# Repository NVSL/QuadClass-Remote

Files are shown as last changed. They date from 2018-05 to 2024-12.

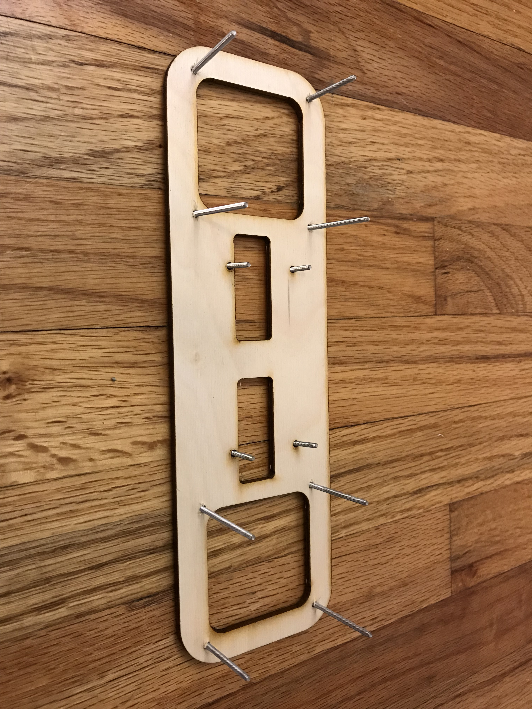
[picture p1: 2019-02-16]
images/IMG_7026.jpg

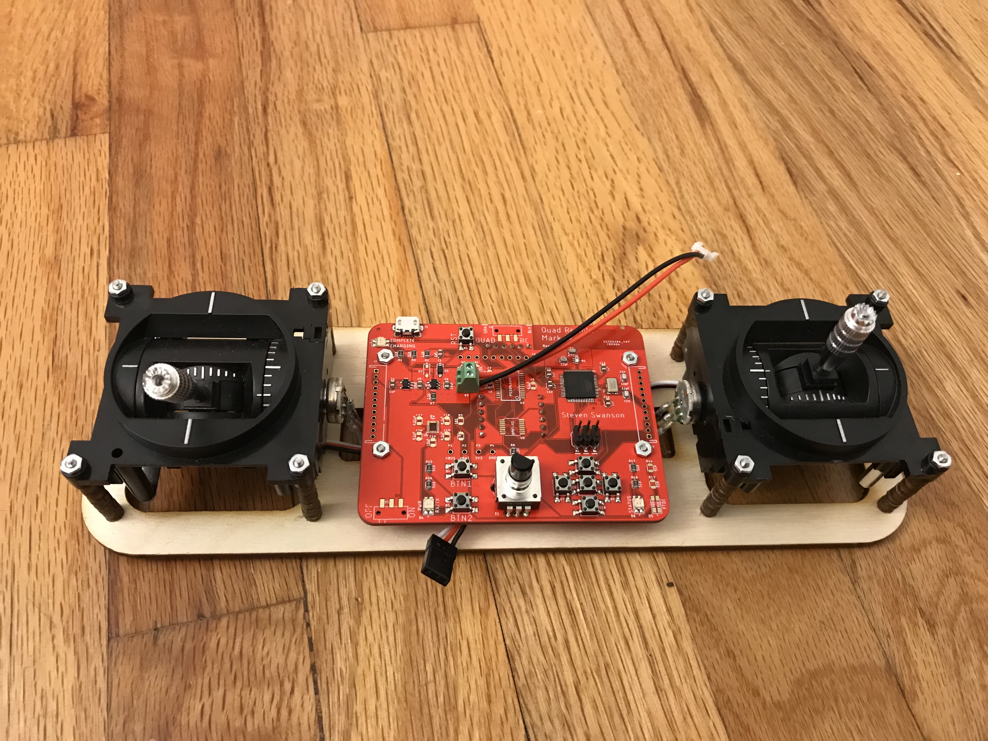
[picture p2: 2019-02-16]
images/IMG_7029.jpg

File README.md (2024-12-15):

# CSE176e Quad Remote

## Assembly

## Parts

All the parts are on the course unified BOM: https://docs.google.com/spreadsheets/d/1jt7lCU-Biuc4YyG8EaISPEg1VLbqKCh2ZZRz8jerXEI/edit?gid=0#gid=0

## Laser Cutting

The plywood base and the "donuts" used for standoffs are all in the
`.brd` file.  Open it, hide everything but the `baseplate` layer.
Print it to a PDF and feed it to your laser cutter.

The wooden parts are cut from 3mm plywood (see parts list).

## The Gimbals

The gimbals attach to the baseplate with the 8 long machine screws and 8 nuts.  

## Board

The control board mounts to the baseplate using the shorter screws and nuts.  Use 3 donuts to put space between the board and the baseplate.

## Battery Cable

Red is positive.

Attach the battery and tuck it under the board.  You can trim the battery cable, if you want.  Experiment with different lengths.

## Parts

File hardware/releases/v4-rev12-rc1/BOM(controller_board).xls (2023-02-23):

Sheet: bom-sample
Controller Board BOM Rev.11
Manufacturer | Manufacturer Part Number (required) | Designator (required) | Qty (required) | Description (required) | Case | SMD ,BGA,LCC,OR TH | Top/Bottom | points (number of contacts the IC has in each board) | Total points (number of contacts per BOM line has) | Comment | DIST | DISTPN
Yageo | RC0603JR-070RL | R7 | 1 | RES 0 OHM JUMPER 1/10W 0603 | 603 | SMD | Top | 2 | 2 |  | Digikey | 311-0.0GRCT-ND
Samsung Electro-Mechanics | DNP | C10, C17 | 2 | CAP CER 1UF 10V X5R 0603 | 603 | SMD | Top | 2 | 4 |  | Digikey | DNP
Texas Instruments | DNP | U1 | 1 | IC REG LINEAR 3.3V 150MA SC70-5 | SOT23-5 | SMD | Top | 5 | 5 |  | DIGIKEY | DNP
Yageo | CC0603BRNPO9BNR75 | C2 | 1 | CAP CER 0.75PF 50V NPO 0603 | 603 | SMD | Top | 2 | 2 |  | Digikey | 311-3843-1-ND
Panasonic Electronic Components | EXB-N8V221JX | R1 | 1 | RES ARRAY 4 RES 220 OHM 0804 | 804 | SMD | Top | 8 | 8 |  | DIGIKEY | Y10222CT-ND
TE Connectivity AMP Connectors | 1-1735446-2 | J2 | 1 | CONN HEADER VERT 12POS 2MM | N/A | TH | Top | 12 | 12 |  | Digikey | A100106-ND
TE Connectivity AMP Connectors | 1-1735446-2 | J3 | 1 | CONN HEADER VERT 12POS 2MM | N/A | TH | Top | 12 | 12 |  | Digikey | A100106-ND
AVX Corporation | 06036A220KAT2A | C3 | 1 | CAP CER 22PF 6.3V NP0 0603 | 603 | SMD | Top | 2 | 2 |  | Digikey | 478-11384-1-ND
NA | DNP | A1 | 1 | trace antenna | N/A | NONE | Top | 0 | 0 |  | N/A | DNP
Microchip Technology | ATMEGA128RFA1-ZU | U4 | 1 | IC RF TXRX+MCU 802.15.4 64VFQFN | 64-QFN | SMD | Top | 64 | 64 |  | Digikey | ATMEGA128RFA1-ZU-ND
Amphenol ICC (FCI) | 95278-101A06LF | J4 | 1 | CONN HEADER SMD 6POS 2.54MM | N/A | SMD | Top | 6 | 6 |  | Digikey | 609-3487-1-ND
Wurth Electronics Inc. | 748421245 | B2 | 1 | BALUN 2.4GHZ-2.5GHZ 50/100 0805 | 805 | SMD | Top | 6 | 6 |  | Digikey | 732-2230-1-ND
Wurth Electronics Inc. | 691210910002 | B3 | 1 | TERM BLOCK 2P HORIZON 2.54MM PCB | N/A | TH | Top | 2 | 2 |  | Digikey | 732-691210910002-ND
Abracon LLC | ABM8-16.000MHZ-B2-T | Y1 | 1 | CRYSTAL 16.0000MHZ 18PF SMD | 4-SMD | SMD | Top | 4 | 4 |  | DIGIKEY | 535-9134-1-ND
NXP USA Inc. | NX3L2467PW,118 | U5 | 1 | IC ANALOG SWITCH DPDT 16TSSOP | 16-TSSOP | SMD | Top | 16 | 16 |  | DIGIKEY | 568-5300-1-ND
FTDI | FT232RL-REEL | U3 | 1 | USB FULL SPEED TO SERIAL UART IC | 28-SSOP | SMD | Top | 28 | 28 |  | DIGIKEY | 768-1007-1-ND
Samtec Inc. | TSM-102-01-L-DH | J6 | 1 | CONN HEADER SMD R/A 4POS 2.54MM | N/A | SMD | Top | 4 | 4 |  | DIGIKEY | SAM15344-ND
Harwin Inc. | DNP | JP1 | 1 | CONN HEADER SMD R/A 6POS 2.54MM | N/A | SMD | Bottom | 6 | 6 |  | DIGIKEY | DNP
On Shore Technology Inc. | DNP | J8 | 1 | TERM BLK 2P SIDE ENT 2.54MM PCB | N/A | TH | Top | 2 | 2 |  | Digikey | DNP
Sullins Connector Solutions | DNP | J9 | 1 | CONN HDR 12POS 0.1 TIN PCB | N/A | TH | Top | 12 | 12 |  | DIGIKEY | DNP
Microchip Technology | MCP73831T-2ACI/OT | U2 | 1 | IC CONTROLLR LI-ION 4.2V SOT23-5 | SOT23-5 | SMD | Top | 5 | 5 |  | DIGIKEY | MCP73831T-2ACI/OTCT-ND
Bourns Inc. | PEC12R-4220F-S0024 | E1 | 1 | ROTARY ENCODER MECHANICAL 24PPR | N/A | TH | Top | 7 | 7 |  | DIGIKEY | PEC12R-4220F-S0024
None | DNP | F1 | 1 | SHORT | N/A | NONE | Top | 0 | 0 |  | N/A | DNP
Sullins Connector Solutions | NPPC101KFXC-RC | L1 | 1 | 10 Position Header, Top or Bottom Entry Connector Surface Mount | N/A | SMD | Top | 10 | 10 |  | Digikey | S5641-ND
Amphenol ICC (FCI) | 10118192-0001LF | J1 | 1 | CONN RCPT USB2.0 MICRO B SMD R/A | USB-microB | SMD | Top | 7 | 7 |  | DIGIKEY | 609-4613-1-ND
Panasonic Electronic Components | EXB-N8V152JX | R4, R5 | 2 | RES ARRAY 4 RES 1.5K OHM 0804 | 804 | SMD | Top | 8 | 16 |  | DIGIKEY | Y10152CT-ND
Vishay Vitramon | VJ0603A120FXQCW1BC | C14, C15 | 2 | CAP CER 12PF 10V C0G/NP0 0603 | 603 | SMD | Top | 2 | 4 |  | Digikey | 720-1655-1-ND
Toshiba Semiconductor and Storage | CRS08(TE85L,Q,M) | D2, D3 | 2 | DIODE SCHOTTKY 30V 1.5A SFLAT | SOD-123F | SMD | Top | 2 | 4 |  | Digikey | CRS08QMCT-ND
Molex | 532610671 | J5, J7 | 2 | CONN HEADER SMD R/A 6POS 1.25MM | N/A | SMD | Top | 6 | 12 |  | DIGIKEY | WM7624CT-ND
C&K | JS202011JCQN | S1, S2 | 2 | SWITCH SLIDE DPDT 300MA 6V | N/A | SMD | Top | 6 | 12 |  | DIGIKEY | CKN10723CT-ND
Panasonic Electronic Components | EXB-N8V103JX | R2, R3, R6 | 3 | RES ARRAY 4 RES 10K OHM 0804 | 804 | SMD | Top | 8 | 24 |  | DIGIKEY | Y10103CT-ND
KEMET | C0603C104K8RACTU | C1, C8, C9 | 3 | CAP CER 0.1UF 10V X7R 0603 | 603 | SMD | Top | 2 | 6 |  | Digikey | 399-1095-1-ND
Samsung Electro-Mechanics | CL10A106MQ8NNNC | C5, C6, C7 | 3 | CAP CER 10UF 6.3V X5R 0603 | 603 | SMD | Top | 2 | 6 |  | Digikey | 1276-1119-1-ND
Lite-On Inc. | LTST-C195TGKRKT | D1, D4, D5, D6 | 4 | LED GREEN/RED CLEAR CHIP SMD | 4-SMD | SMD | Top | 4 | 16 |  | DIGIKEY | 160-2252-1-ND
Samsung Electro-Mechanics | CL10A105KP8NNNC | C4, C11, C12, C13, C16 | 5 | CAP CER 1UF 10V X5R 0603 | 603 | SMD | Top | 2 | 10 |  | Digikey | 1276-1182-1-ND
E-Switch | TL3305AF160QG | B1, B4, B5, B6, B7, B8, B9, B10 | 8 | SWITCH TACTILE SPST-NO 50MA 12V | N/A | SMD | Top | 4 | 32 |  | DIGIKEY | EG5350CT-ND
NA | DNP | V1, V2, V3, V4, V5, V6, V7, V8, V23, V24, V26, V27, V28, V30, V31, V32, V33, V34, V35, V36, V37, V38 | 22 | N/A | N/A | NONE | Top | 0 | 0 |  | N/A | DNP

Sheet: (ignore)4_Digikey-BOM
4 | 311-3843-1-ND | (controller_board) Yageo
4 | Y10222CT-ND | (controller_board) Panasonic Electronic Components
4 | A100106-ND | (controller_board) TE Connectivity AMP Connectors
4 | A100106-ND | (controller_board) TE Connectivity AMP Connectors
4 | 478-11384-1-ND | (controller_board) AVX Corporation
4 | DNP | (controller_board) NA
4 | ATMEGA128RFA1-ZU-ND | (controller_board) Microchip Technology
4 | 609-3487-1-ND | (controller_board) Amphenol ICC (FCI)
4 | 732-2230-1-ND | (controller_board) Wurth Electronics Inc.
4 | 732-691210910002-ND | (controller_board) Wurth Electronics Inc.
4 | 535-9134-1-ND | (controller_board) Abracon LLC
4 | 568-5300-1-ND | (controller_board) NXP USA Inc.
4 | 768-1007-1-ND | (controller_board) FTDI
4 | SAM15344-ND | (controller_board) Samtec Inc.
4 | DNP | (controller_board) Harwin Inc.
4 | DNP | (controller_board) On Shore Technology Inc.
4 | DNP | (controller_board) Sullins Connector Solutions
4 | MCP73831T-2ACI/OTCT-ND | (controller_board) Microchip Technology
4 | PEC12R-4220F-S0024 | (controller_board) Bourns Inc.
4 | DNP | (controller_board) None
4 | S5641-ND | (controller_board) Sullins Connector Solutions
4 | 609-4613-1-ND | (controller_board) Amphenol ICC (FCI)
8 | Y10152CT-ND | (controller_board) Panasonic Electronic Components
8 | 720-1655-1-ND | (controller_board) Vishay Vitramon
8 | CRS08QMCT-ND | (controller_board) Toshiba Semiconductor and Storage
8 | WM7624CT-ND | (controller_board) Molex
8 | CKN10723CT-ND | (controller_board) C&K
12 | Y10103CT-ND | (controller_board) Panasonic Electronic Components
12 | 399-1095-1-ND | (controller_board) KEMET
12 | 1276-1119-1-ND | (controller_board) Samsung Electro-Mechanics
16 | 160-2252-1-ND | (controller_board) Lite-On Inc.
20 | 1276-1182-1-ND | (controller_board) Samsung Electro-Mechanics
32 | EG5350CT-ND | (controller_board) E-Switch
88 | DNP | (controller_board) NA

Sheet: (ignore)50_Digikey-BOM
50 | 311-3843-1-ND | (controller_board) Yageo
50 | Y10222CT-ND | (controller_board) Panasonic Electronic Components
50 | A100106-ND | (controller_board) TE Connectivity AMP Connectors
50 | A100106-ND | (controller_board) TE Connectivity AMP Connectors
50 | 478-11384-1-ND | (controller_board) AVX Corporation
50 | DNP | (controller_board) NA
50 | ATMEGA128RFA1-ZU-ND | (controller_board) Microchip Technology
50 | 609-3487-1-ND | (controller_board) Amphenol ICC (FCI)
50 | 732-2230-1-ND | (controller_board) Wurth Electronics Inc.
50 | 732-691210910002-ND | (controller_board) Wurth Electronics Inc.
50 | 535-9134-1-ND | (controller_board) Abracon LLC
50 | 568-5300-1-ND | (controller_board) NXP USA Inc.
50 | 768-1007-1-ND | (controller_board) FTDI
50 | SAM15344-ND | (controller_board) Samtec Inc.
50 | DNP | (controller_board) Harwin Inc.
50 | DNP | (controller_board) On Shore Technology Inc.
50 | DNP | (controller_board) Sullins Connector Solutions
50 | MCP73831T-2ACI/OTCT-ND | (controller_board) Microchip Technology
50 | PEC12R-4220F-S0024 | (controller_board) Bourns Inc.
50 | DNP | (controller_board) None
50 | S5641-ND | (controller_board) Sullins Connector Solutions
50 | 609-4613-1-ND | (controller_board) Amphenol ICC (FCI)
100 | Y10152CT-ND | (controller_board) Panasonic Electronic Components
100 | 720-1655-1-ND | (controller_board) Vishay Vitramon
100 | CRS08QMCT-ND | (controller_board) Toshiba Semiconductor and Storage
100 | WM7624CT-ND | (controller_board) Molex
100 | CKN10723CT-ND | (controller_board) C&K
150 | Y10103CT-ND | (controller_board) Panasonic Electronic Components
150 | 399-1095-1-ND | (controller_board) KEMET
150 | 1276-1119-1-ND | (controller_board) Samsung Electro-Mechanics
200 | 160-2252-1-ND | (controller_board) Lite-On Inc.
250 | 1276-1182-1-ND | (controller_board) Samsung Electro-Mechanics
400 | EG5350CT-ND | (controller_board) E-Switch
1100 | DNP | (controller_board) NA

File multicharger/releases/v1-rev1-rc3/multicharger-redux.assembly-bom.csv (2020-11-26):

mfr | mfrpn | dist | distpn | part_list | qty | desc | substitute_ok | case | mounting | layer | pins | extended_pins | comments
Keystone Electronics | 931 | DIGIKEY | 36-931-ND | J2 | 1 | CONN PLUG USB2.0 TYPEA 4P SMD RA | no |  | SMD | top | 6 | 6
Microchip Technology | MCP73831T-2ACI/OT | DIGIKEY | MCP73831T-2ACI/OTCT-ND | U4 U1 | 2 | IC CONTROLLR LI-ION 4.2V SOT23-5 | no | SOT23-5 | SMD | top | 5 | 10
TDK | C2012X5R1E106K125AB | DIGIKEY | 490-5523-1-ND | C8 C3 C1 C6 | 4 | CAP CER 10UF 25V X5R 0805 | yes |  | SMD | top | 2 | 8
UNKNOWN | UNKNOWN | ALIBABA | https://www.alibaba.com/product-detail/Molex-51005-51006-2-pin-female_60863668004.html | B4 B1 | 2 | Surface mount battery connector | no |  | SMD | top | 4 | 8
Yageo | RC0805FR-071K2L | DIGIKEY | 311-1.20KCRCT-ND | R2 R3 R4 R1 | 4 | RES SMD 1.2K OHM 1% 1/8W 0805 | yes | 0805 | SMD | top | 2 | 8
YAGEO | AC0805FR-071K2L | DIGIKEY | YAG3700CT-ND | R7 R5 | 2 | RES SMD 1.2K OHM 1% 1/8W 0805 | yes | 0805 | SMD | top | 2 | 4
Lite-On Inc. | LTST-C195TGKRKT | DIGIKEY | 160-2252-1-ND | D4 D1 | 2 | LED GREEN/RED CLEAR CHIP SMD | no | 4SMD | SMD | top | 4 | 8

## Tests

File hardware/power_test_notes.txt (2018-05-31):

Design notes for RC1

1.  FTDI works ok, but only the green LED lights up.  Not sure why. -- Fixed
2.  The mux and switches work fine. 
3.  Battery charger seems to charge batteries, but LEDs don't light up.  I can light up green manually.  Red is a no go. -- fixed
4.  Some how blew C8. -- na
5.  Using PWREN to enable the battery charger may not be a good idea.  Will it work with a "wall wart" ***

6.  The solder stencil applied a little too much paste.  I had some bridges on ftdi and mux. -- make sure it's very flat to the board.  Works fine.
7.  When disconnected from USB and connected to power, VBAT sits at 2.7V.  -- powered via switch.
8.  When J5 is not connected to anything, D5 flashes for ever, which suggests that FTDI is resetting. -- unclear.
9.  Connecting VBAT ot FTDI via J5, causes slower flashing.  Maybe something capacitors and the mosfet?  -- unclear
10.  connecting VBUS to FTDI powers it correctly.

11.  The switch chip will drive it's vdd high if you connect power to pins, but leave VDD in floating.
12.  The polarity of my red leds is backwards. WTF???? *******

In order to use them FTDI voltage regulator, we have to have mosfet:  We are driving the FTDI with two different voltage sources: VBUS and VBAT (driven by charger), they are different, so one must be disconnected.  A diode by itself might do...  We can replace the pfet with a diode to prevent current from flowing back onto the battery from vbus.  This seems to work.

13.  The power switch needs to be in a different spot.  Turning it off disables ftdi when connected to VBUS.  Without vbus, FTDI red led is on a bit when switch is off.  Battery charge lites are both on a little --fixed

Current plan:

Assemble second board:

1.  DNP Diode, mosfet, and separate vreg.  mux, too.
2.  Test battery status voltage before assembly.
3.  Test red LEDs.  None of them work.  Did I overdrive them?  100Ohms at 5V > 32mA, which is 2mA over absolute max.  Try 200Ohms.  Shouldn't been a problem for batt charger because outut should be 5V-0.4 => 28mA
4.  Check whether wall wart charging works.

Red leds turn on nicely at 1.6V @ 6mA

V = IR
V = 5-1.6 = 3.4
I = 6mA 
R = V/I = 3.4/6e-3 = 566Ohms.  Using 510 for R6

For Battery charger:

4.6-1.6 = 3
I = 6mA
R = 500 Ohms.  Using 510 for R8

green leds light up nicely at 1.9V 5mA

V = 5-1.9 = 3.1
R = 3.1/5e-3 =620 Ohms

4.6 - 1.9 = 2.7
R = 2.7/5e-3 = 540Ohms

Using 510 for R9 R7

V = 3.3-1.9 = 1.4
R = 1.4=5e-3 = 280Ohms for power LED

Using 270 on R11

V=IR 
V=0.81
r = 510

I = V/R

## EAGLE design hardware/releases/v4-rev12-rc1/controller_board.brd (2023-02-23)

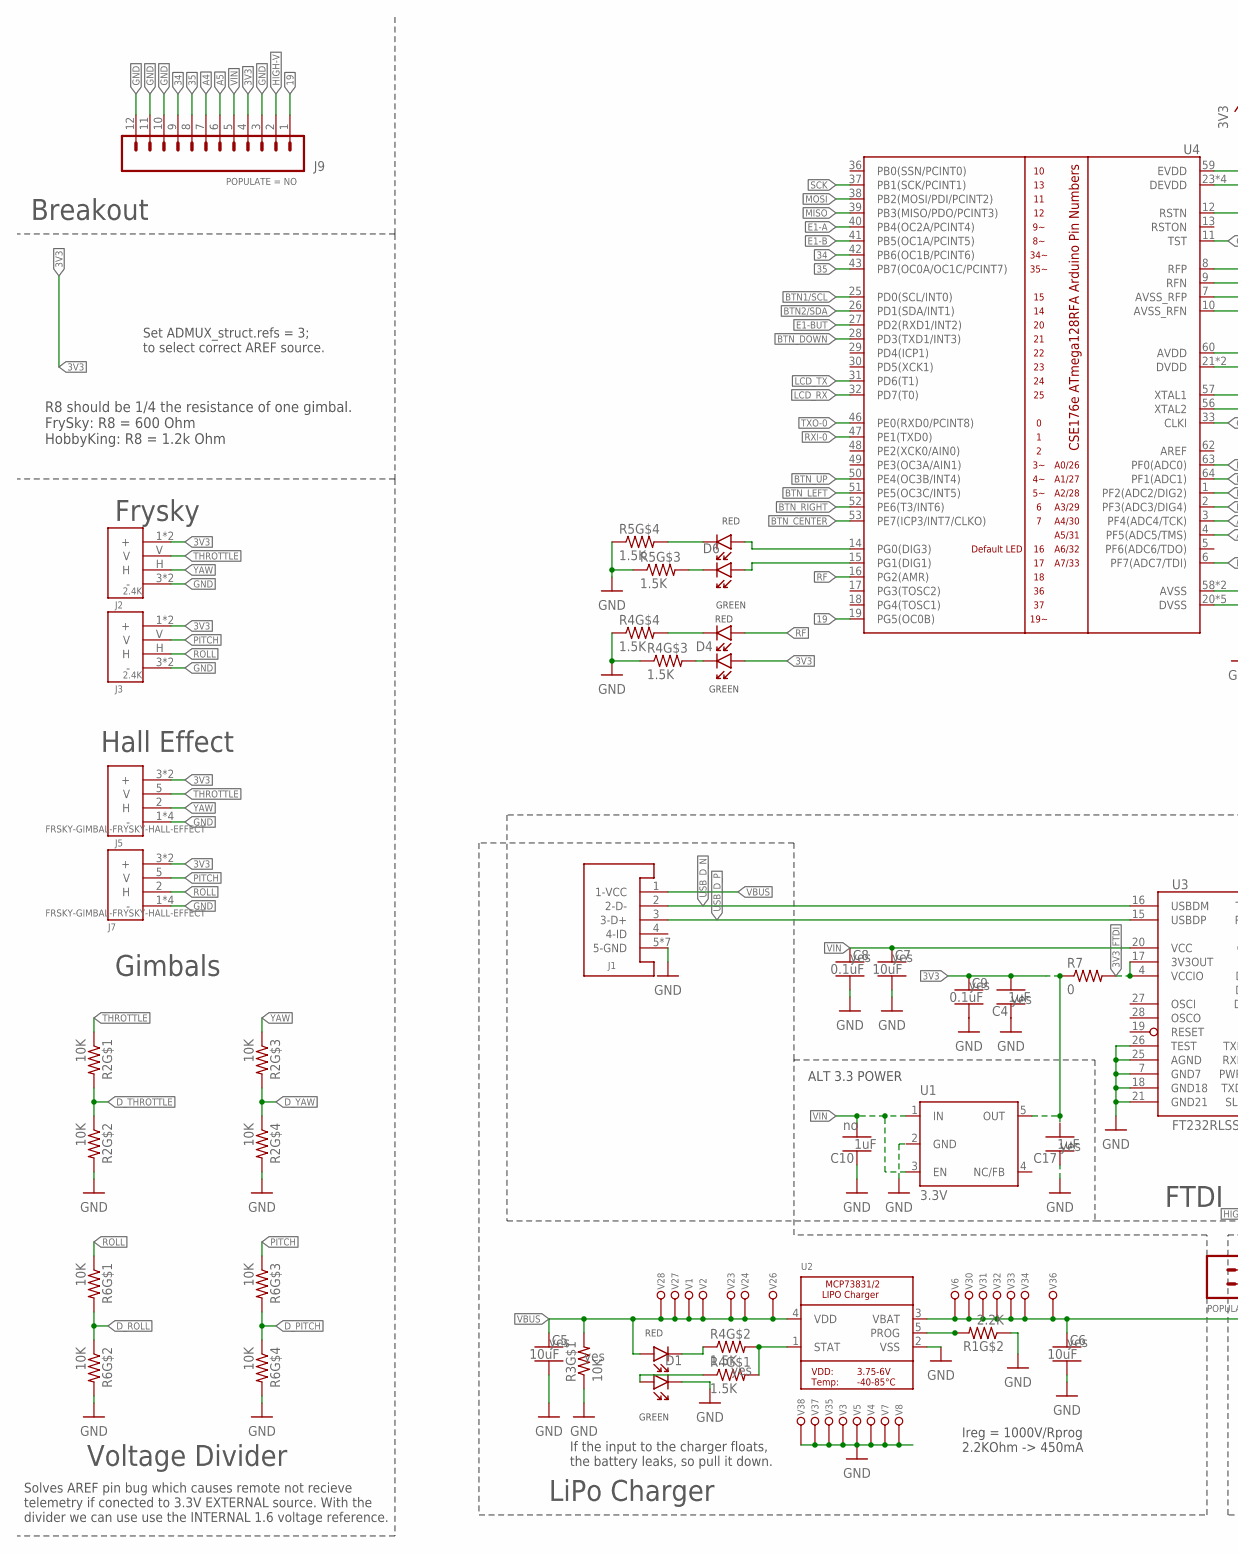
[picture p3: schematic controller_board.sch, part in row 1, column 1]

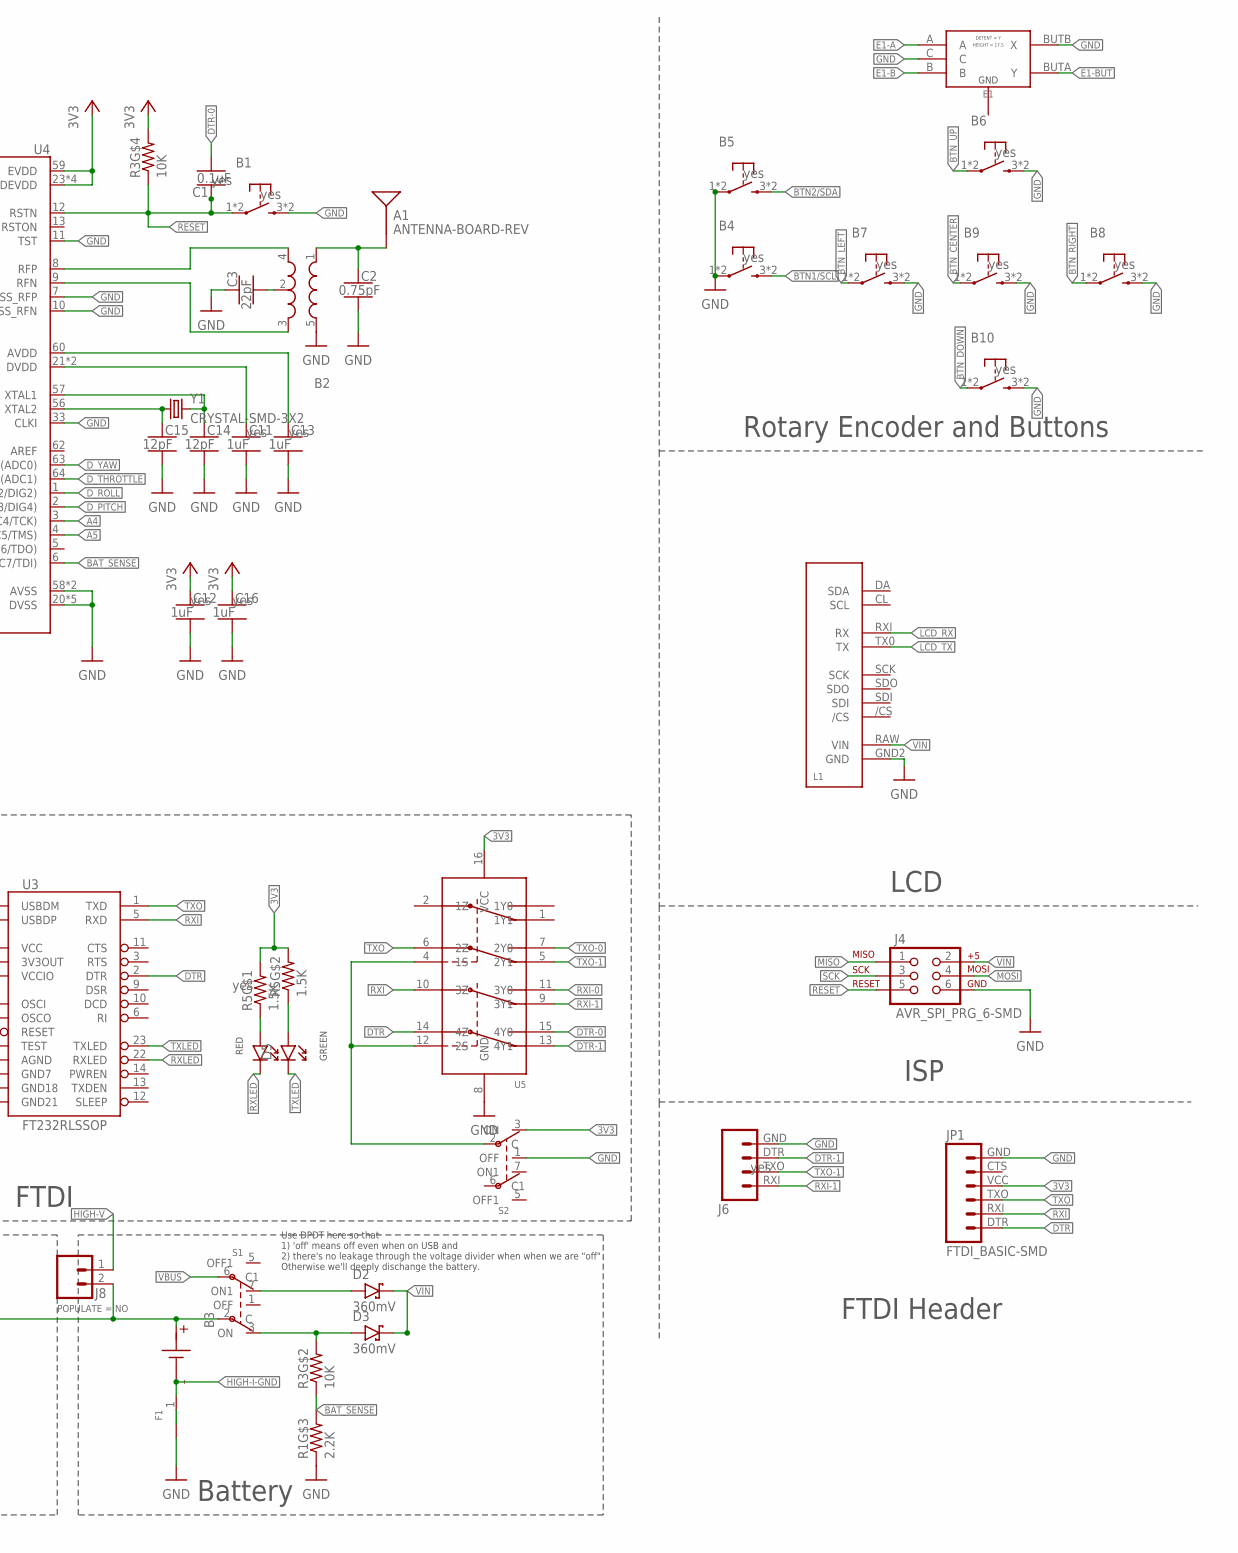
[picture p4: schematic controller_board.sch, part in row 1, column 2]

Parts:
A1: ANTENNA-BOARD-REV; ANT_PCB_2.4GHZ_NRF8001_1.6MM_1OZ_REV
B1, B4, B5, B6, B7, B8, B9, B10: PUSHBUTTON_-4.5X4.5; 4.5MM_TACTILE_SWITCH_TL3305AF160QG
B2: BALUN0805; BALUN
B3: BATTERY-SCREW-TERMINAL; SCREW-TERMINAL-1X2-2.54MM
C1, C8, C9: 0.1uF; CAPC1608X100
C2: 0.75pF; CAPC1608X100
C3: 22pF; CAPC1608X100
C4, C10, C11, C12, C13, C16, C17: 1uF; CAPC1608X100
C5, C6, C7: 10uF; CAPC1608X100
C14, C15: 12pF; CAPC1608X100
D1, D4, D5, D6: LED-2X-GREEN/RED-1.6X1.5MM; LED-2X-LITE-ON-1.6MMX1.5MM
D2, D3: 360mV; SODFL3516X96
E1: ROTARY-ENCODER-W/BUTTON-BOURNS-PEC12R-4217F; BOURNS-PEC12R
F1: SHORT
J1: USB-MICROA-AMPHENOL-10118192-0001LF; USB-MICROA-10118192-0001LF
J2, J3: 2.4K; JST-13-PTH
J4: AVR_SPI_PRG_6-SMD; 2X3-SMD
J5, J7: FRSKY-GIMBAL-FRYSKY-HALL-EFFECT; MOLEX-0532610671
J6: FTDI-4PIN-RIGHT-ANGLE-SMD; HEADER-2X2-0.1IN-MALE-RIGHT-ANGLE-SMD
J8: HEADER-0.1IN-2POS-SCREW; SCREW-TERMINAL-1X2-2.54MM
J9: HEADER-12POS-0.1IN-FEMALE-TH; HDRVR12W75P254_1X12_3098X254X850B
JP1: FTDI_BASIC-SMD; FTDI-BASIC-SMD
L1: SPARKFUN_SERLCD_SERIAL_REDUCED-SMD; SPARKFUN_SERLCD_16X2_REDUCED_SMD
R1: 2.2K; RESCAXS50P200X100X45-8
R2, R3, R6: 10K; RESCAXS50P200X100X45-8
R4, R5: 1.5K; RESCAXS50P200X100X45-8
R7: 0; RESC1608X55
S1, S2: SWITCH-DPDT-300MA-6V-SMD; JS202011JCQN
U1: 3.3V; SOT23-DBV
U2: MCP73831T-2ACI/OT; SOT23-5
U3: FT232RLSSOP; SSOP28DB
U4: ATMEGA128RFA1; QFN-64
U5: DPDT-X2; SOP65P640X110-16
V1, V2, V3, V4, V5, V6, V7, V8, V23, V24, V26, V27, V28, V30, V31, V32, V33, V34, V35, V36, V37, V38: LOCKED-VIA-0.2; VIA-0.2MM
Y1: CRYSTAL-SMD-3X2; OSCCC320X250X85

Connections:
3V3: C4.2, C9.1, C12.1, C16.1, C17.2, D4.A1, J2.1 (+), J2.4 (+), J3.1 (+), J3.4 (+), J5.3 (+), J5.6 (+), J7.3 (+), J7.6 (+), J9.4, JP1.VCC (4), R3.8 (2), R5.5 (2), R5.6 (2), R7.1, S2.3 (ON), U1.5 (OUT), U4.23 (DEVDD), U4.34 (DEVDD), U4.44 (DEVDD), U4.54 (DEVDD), U4.59 (EVDD), U5.16 (VCC)
3V3_FTDI: R7.2, U3.4 (VCCIO), U3.17 (3V3OUT)
19: J9.1, U4.19 (PG5(OC0B))
34: J9.9, U4.42 (PB6(OC1B/PCINT6))
35: J9.8, U4.43 (PB7(OC0A/OC1C/PCINT7))
A4: J9.7, U4.3 (PF4(ADC4/TCK))
A5: J9.6, U4.4 (PF5(ADC5/TMS))
ANTENNA: A1.FEED, B2.1 (IN), C2.1
BAT_SENSE: R1.7 (2), R3.3 (1), U4.6 (PF7(ADC7/TDI))
BCAP: B2.2 (GND), C3.2
BPOS: B3.2, C6.1, J8.2 (1), S1.2 (C), U2.3 (VBAT), V6.P1, V30.P1, V31.P1, V32.P1, V33.P1, V34.P1, V36.P1
BTN1/SCL: B4.3 (2), B4.4 (2), U4.25 (PD0(SCL/INT0))
BTN2/SDA: B5.3 (2), B5.4 (2), U4.26 (PD1(SDA/INT1))
BTN_CENTER: B9.1, B9.2 (1), U4.53 (PE7(ICP3/INT7/CLKO))
BTN_DOWN: B10.1, B10.2 (1), U4.28 (PD3(TXD1/INT3))
BTN_LEFT: B7.1, B7.2 (1), U4.51 (PE5(OC3C/INT5))
BTN_RIGHT: B8.1, B8.2 (1), U4.52 (PE6(T3/INT6))
BTN_UP: B6.1, B6.2 (1), U4.50 (PE4(OC3B/INT4))
CLK_NEG: C15.1, U4.56 (XTAL2), Y1.1
CLK_POS: C14.1, U4.57 (XTAL1), Y1.3 (2)
DTR: JP1.DTR (1), U3.2 (DTR), U5.14 (4Z)
DTR-0: C1.2, U5.15 (4Y0)
DTR-1: J6.DTR (3), U5.13 (4Y1)
D_PITCH: R6.1, R6.7 (2), U4.2 (PF3(ADC3/DIG4))
D_ROLL: R6.3 (1), R6.5 (2), U4.1 (PF2(ADC2/DIG2))
D_THROTTLE: R2.3 (1), R2.5 (2), U4.64 (PF1(ADC1))
D_YAW: R2.1, R2.7 (2), U4.63 (PF0(ADC0))
E1-A: E1.A, U4.40 (PB4(OC2A/PCINT4))
E1-B: E1.B, U4.41 (PB5(OC1A/PCINT5))
E1-BUT: E1.BUTA (Y), U4.27 (PD2(RXD1/INT2))
GND: B1.3 (2), B1.4 (2), B2.5 (GND), B4.1, B4.2 (1), B5.1, B5.2 (1), B6.3 (2), B6.4 (2), B7.3 (2), B7.4 (2), B8.3 (2), B8.4 (2), B9.3 (2), B9.4 (2), B10.3 (2), B10.4 (2), C2.2, C3.1, C4.1, C5.2, C6.2, C7.2, C8.2, C9.2, C10.1, C11.2, C12.2, C13.2, C14.2, C15.2, C16.2, C17.1, D1.C1, E1.BUTB (X), E1.C, F1.2 (B), J1.5 (5-GND), J1.6 (5-GND), J1.7 (5-GND), J1.8 (5-GND), J1.9 (5-GND), J1.10 (5-GND), J1.11 (5-GND), J2.3 (-), J2.6 (-), J3.3 (-), J3.6 (-), J4.6, J5.1 (-), J5.4 (-), J5.G1 (-), J5.G2 (-), J6.GND (4), J7.1 (-), J7.4 (-), J7.G1 (-), J7.G2 (-), J9.3, J9.10, J9.11, J9.12, JP1.GND (6), L1.GND2 (GND), R1.2 (1), R1.3 (1), R2.6 (2), R2.8 (2), R3.4 (1), R4.1, R4.2 (1), R5.1, R5.2 (1), R6.6 (2), R6.8 (2), S2.1 (OFF), U1.2 (GND), U2.2 (VSS), U3.7 (GND7), U3.18 (GND18), U3.21 (GND21), U3.25 (AGND), U3.26 (TEST), U4.7 (AVSS_RFP), U4.10 (AVSS_RFN), U4.11 (TST), U4.20 (DVSS), U4.24 (DVSS), U4.33 (CLKI), U4.35 (DVSS), U4.45 (DVSS), U4.55 (DVSS), U4.58 (AVSS), U4.61 (AVSS), U5.8 (GND), V3.P1, V4.P1, V5.P1, V7.P1, V8.P1, V35.P1, V37.P1, V38.P1
HIGH-I-GND: B3.1 (N), F1.1 (A)
HIGH-V: J8.1 (2), J9.2
LCD_RX: L1.RXI (RX), U4.32 (PD7(T0))
LCD_TX: L1.TX0 (TX), U4.31 (PD6(T1))
MISO: J4.1, U4.39 (PB3(MISO/PDO/PCINT3))
MOSI: J4.4, U4.38 (PB2(MOSI/PDI/PCINT2))
unnamed: D1.A1, R4.4 (1)
unnamed: D1.C2, R4.3 (1)
unnamed: D5.A1, R5.3 (1)
unnamed: D6.C2, R5.8 (2)
unnamed: D6.C1, R5.7 (2)
unnamed: D4.C1, R4.7 (2)
unnamed: D5.A2, R5.4 (1)
unnamed: D6.A2, U4.14 (PG0(DIG3))
unnamed: D6.A1, U4.15 (PG1(DIG1))
unnamed: R4.5 (2), R4.6 (2), U2.1 (STAT)
unnamed: R1.6 (2), U2.5 (PROG)
unnamed: D4.C2, R4.8 (2)
unnamed: D2.2 (A), S1.7 (ON1)
unnamed: C11.1, U4.21 (DVDD), U4.22 (DVDD)
unnamed: C13.1, U4.60 (AVDD)
PITCH: J3.V, J7.5 (V), R6.2 (1)
PROG_SEL: S2.2 (C), U5.4 (1S), U5.12 (2S)
RESET: B1.1, B1.2 (1), C1.1, J4.5, R3.1, U4.12 (RSTN)
RF: D4.A2, U4.16 (PG2(AMR))
RF_N: B2.3 (OUT2), U4.9 (RFN)
RF_P: B2.4 (OUT1), U4.8 (RFP)
ROLL: J3.H, J7.2 (H), R6.4 (1)
RXI: JP1.RXI (2), U3.5 (RXD), U5.10 (3Z)
RXI-0: U4.47 (PE1(TXD0)), U5.11 (3Y0)
RXI-1: J6.RXI (1), U5.9 (3Y1)
RXLED: D5.C2, U3.22 (RXLED)
SCK: J4.3, U4.37 (PB1(SCK/PCINT1))
THROTTLE: J2.V, J5.5 (V), R2.4 (1)
TXLED: D5.C1, U3.23 (TXLED)
TXO: JP1.TXO (3), U3.1 (TXD), U5.6 (2Z)
TXO-0: U4.46 (PE0(RXD0/PCINT8)), U5.7 (2Y0)
TXO-1: J6.TXO (2), U5.5 (2Y1)
USB_D_N: J1.2 (2-D-), U3.16 (USBDM)
USB_D_P: J1.3 (3-D+), U3.15 (USBDP)
VBAT: D3.2 (A), R3.6 (2), S1.3 (ON)
VBUS: C5.1, D1.A2, J1.1 (1-VCC), R3.5 (2), S1.6 (C1), U2.4 (VDD), V1.P1, V2.P1, V23.P1, V24.P1, V26.P1, V27.P1, V28.P1
VIN: C7.1, C8.1, C10.2, D2.1 (C), D3.1 (C), J4.2, J9.5, L1.RAW (VIN), U1.1 (IN), U1.3 (EN), U3.20 (VCC)
YAW: J2.H, J5.2 (H), R2.2 (1)

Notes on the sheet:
Ireg = 1000V/Rprog 2.2KOhm -> 450mA
LiPo Charger
Breakout
Frysky
Hall Effect
Rotary Encoder and Buttons
Battery
LCD
ISP
FTDI Header
Set ADMUX_struct.refs = 3; to select correct AREF source.
Gimbals
R8 should be 1/4 the resistance of one gimbal. FrySky: R8 = 600 Ohm HobbyKing: R8 = 1.2k Ohm
If the input to the charger floats, the battery leaks, so pull it down.
FTDI
Use DPDT here so that 1) 'off' means off even when on USB and 2) there's no leakage through the voltage divider when when we are "off" Otherwise we'll deeply dischange the battery.
Voltage Divider
Solves AREF pin bug which causes remote not recieve telemetry if conected to 3.3V EXTERNAL source. With the divider we can use use the INTERNAL 1.6 voltage reference.
ALT 3.3 POWER

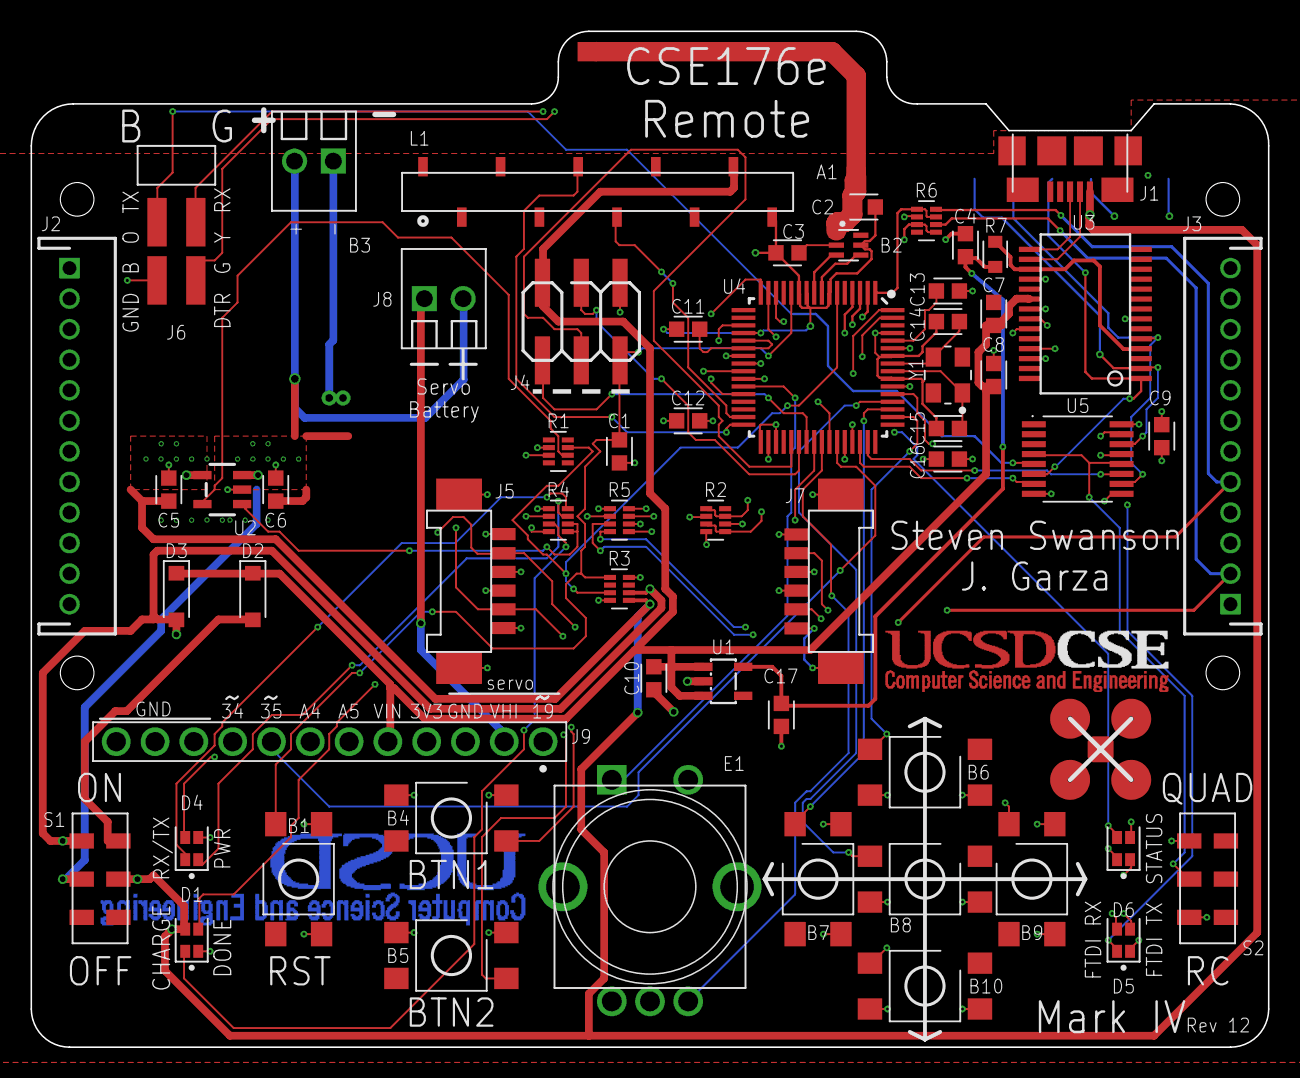
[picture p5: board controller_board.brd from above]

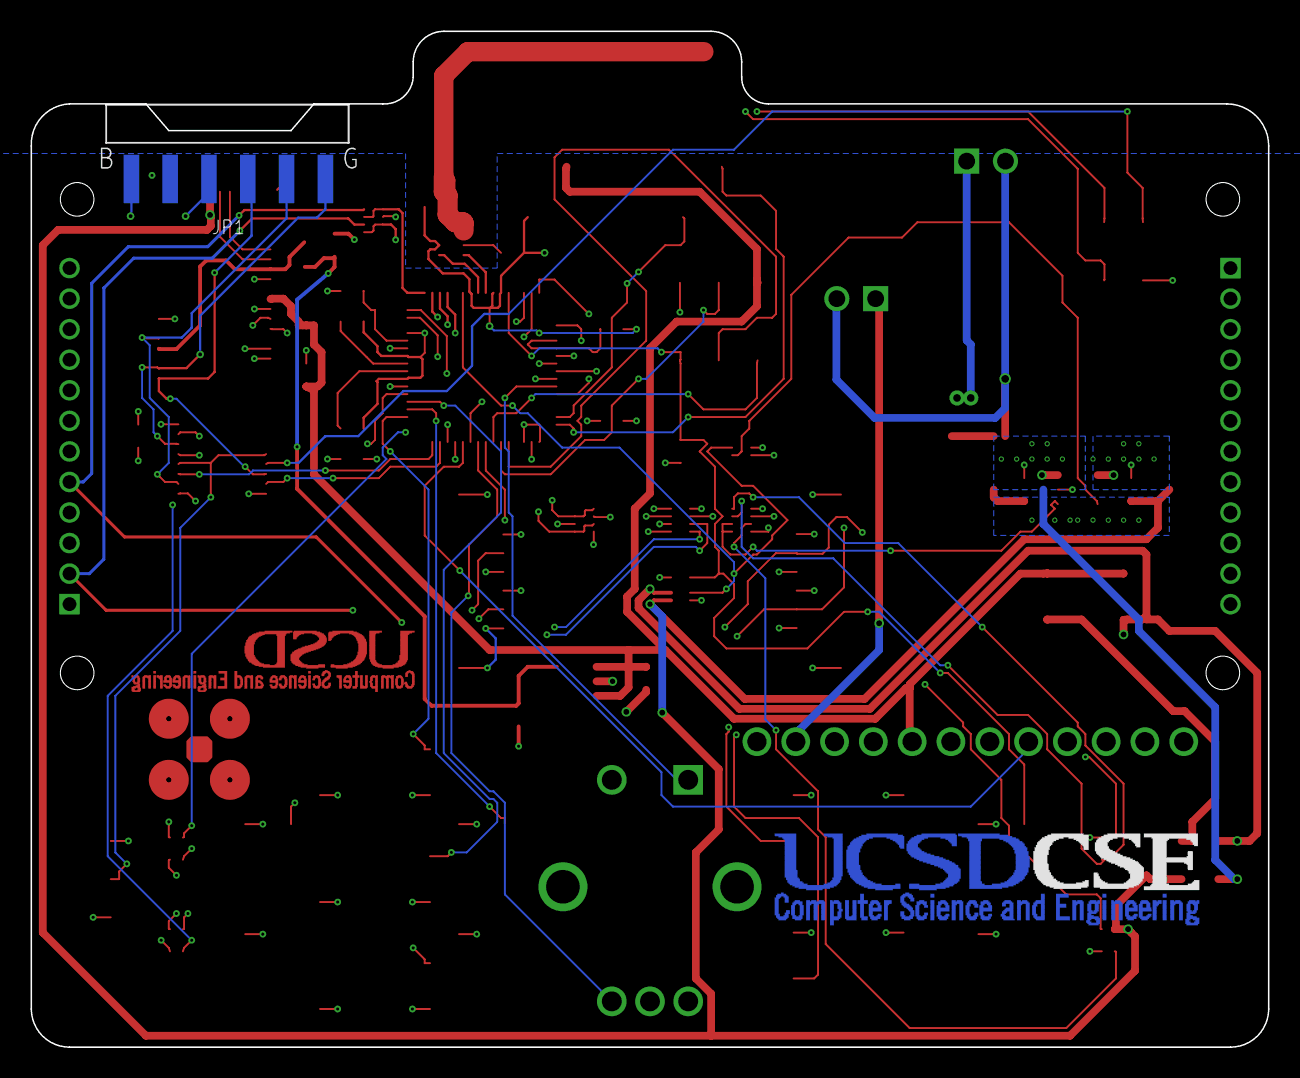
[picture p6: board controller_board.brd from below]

Board: 4 copper layers, 81.0 x 66.5 mm, 93 parts (2 on the bottom side), 75 nets.

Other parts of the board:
E$1, E$2: FRSKY-TARANIS-GIMBAL
U$1: 700MAH-BATTERY
U$2: QUADCLASS_LOGO_SMALL
U$3: LAYER_LABELS
U$4: 375MAH-BATTERY
U$5: 600MAH-BATTERY
U$6, U$7: CSE

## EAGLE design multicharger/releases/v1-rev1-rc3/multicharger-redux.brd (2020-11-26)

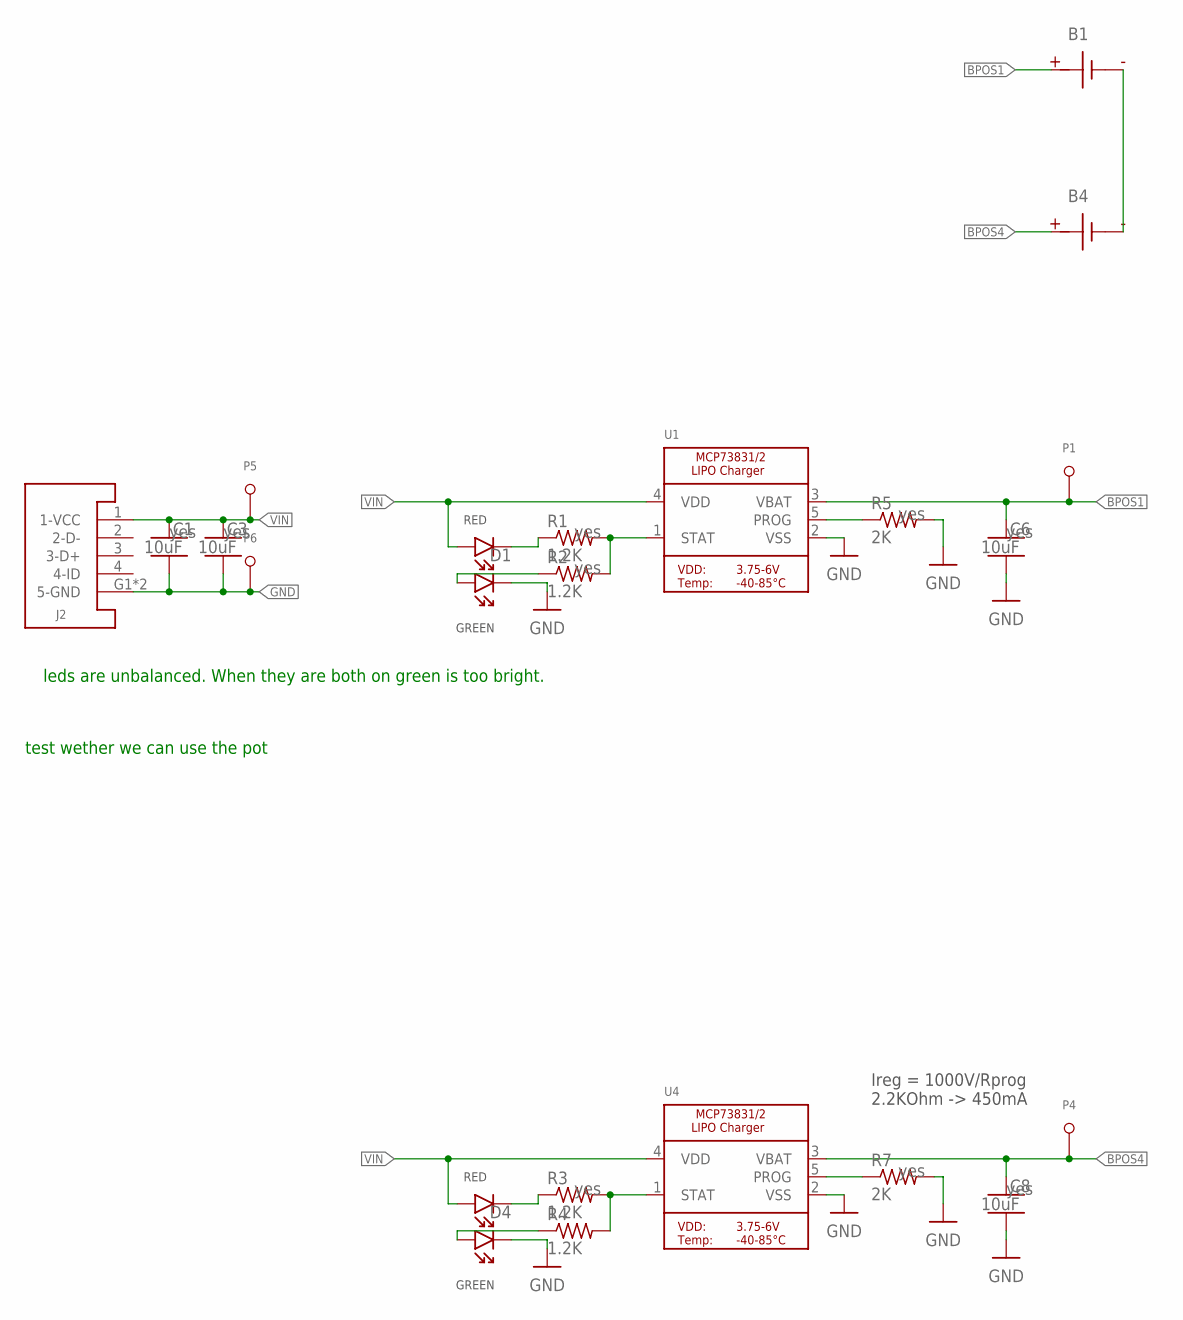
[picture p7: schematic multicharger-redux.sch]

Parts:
B1, B4: BATTERY-SMD; MOLEX-BATTERY-CONNECTOR-SMD-51005-2P
C1, C3, C6, C8: 10uF; CAPC2012X140_HS
D1, D4: LED-2X-GREEN/RED-1.6X1.5MM; LED-2X-LITE-ON-1.6MMX1.5MM
J2: USB-A-SMD-KEYSTONE-931; USB-A-KEYSTONE-931
P1, P4, P5, P6: TEST-POINT-1MM; TEST-POINT-1MM-VIA
R1, R2, R3, R4: 1.2K; RESC2012X60_HS
R5, R7: 2K; RESC2012X60_HS
U1, U4: MCP73831T-2ACI/OT; SOT23-5

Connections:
BPOS1: B1.P, C6.1, P1.T, U1.3 (VBAT)
BPOS4: B4.P, C8.1, P4.T, U4.3 (VBAT)
GND: B1.G (N), B1.G2 (N), B1.G3 (N), B4.G (N), B4.G2 (N), B4.G3 (N), C1.2, C3.2, C6.2, C8.2, D1.C1, D4.C1, J2.G1 (5-GND), J2.G2 (5-GND), P6.T, R5.2, R7.2, U1.2 (VSS), U4.2 (VSS)
unnamed: D1.A1, R2.1
unnamed: D1.C2, R1.1
unnamed: R1.2, R2.2, U1.1 (STAT)
unnamed: R5.1, U1.5 (PROG)
unnamed: R3.2, R4.2, U4.1 (STAT)
unnamed: R7.1, U4.5 (PROG)
unnamed: D4.A1, R4.1
unnamed: D4.C2, R3.1
VIN: C1.1, C3.1, D1.A2, D4.A2, J2.1 (1-VCC), P5.T, U1.4 (VDD), U4.4 (VDD)

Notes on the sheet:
Ireg = 1000V/Rprog 2.2KOhm -> 450mA
leds are unbalanced. When they are both on green is too bright.
test wether we can use the pot

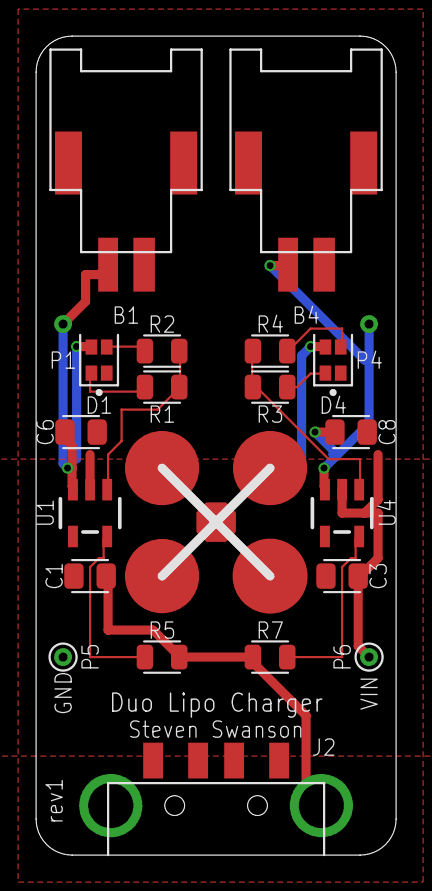
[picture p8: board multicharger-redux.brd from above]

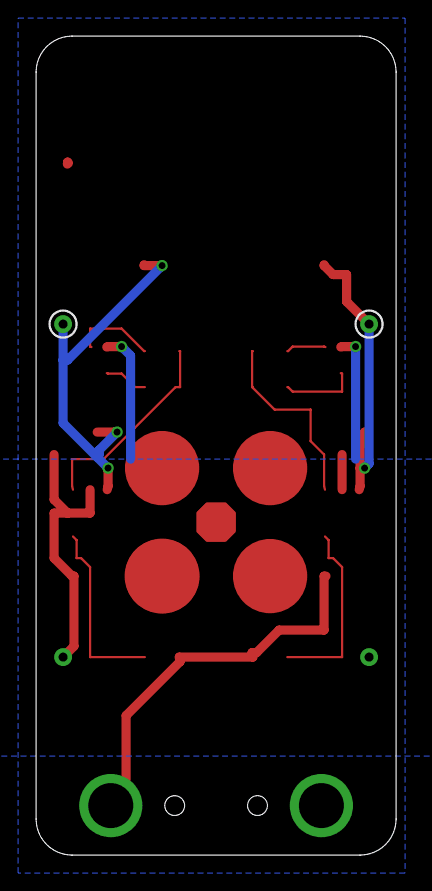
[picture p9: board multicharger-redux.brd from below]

Board: 4 copper layers, 20.0 x 45.5 mm, 22 parts (2 on the bottom side), 12 nets.

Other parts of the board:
U$2: QUADCLASS_LOGO

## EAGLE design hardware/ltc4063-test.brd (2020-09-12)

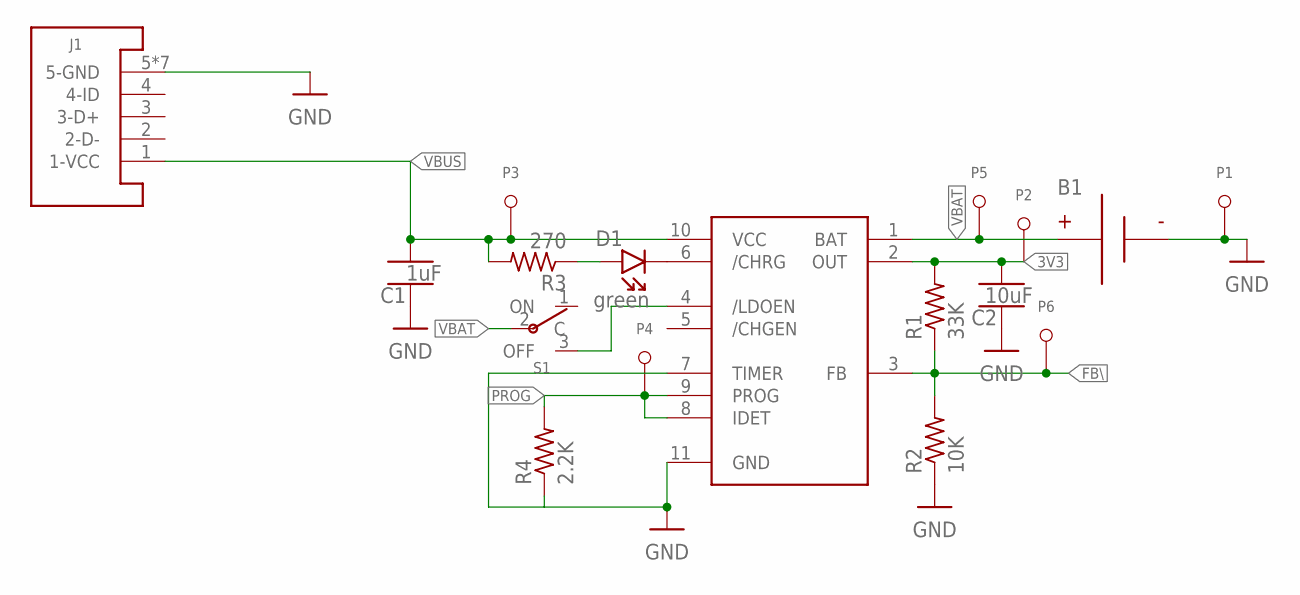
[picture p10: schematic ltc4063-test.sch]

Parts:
B1: BATTERY-SPRING-SMD; WIRE-TERMINAL-1X2-2.5MM-SMD-AVX-009276002021106
C1: 1uF; CAPC2012X140_HS
C2: 10uF; CAPC2012X140_HS
D1: green; LEDSC125X200X120-2_HS
J1: USB-MICROA-AMPHENOL-10118192-0001LF; USB-MICROA-10118192-0001LF
P1, P2, P3, P4, P5, P6: TEST-POINT; TEST-POINT-KEYSTONE-5000
R1: 33K; RESC2012X60_HS
R2: 10K; RESC2012X60_HS
R3: 270; RESC2012X60_HS
R4: 2.2K; RESC2012X60_HS
S1: POWER-SWITCH-MFS201N-9-Z-SMD-VERTICAL; JS102011JCQN
U1: LIPO-VREG-LTC4063; SON50P300X300X80-11T165X238

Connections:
3V3: C2.2, P2.T, R1.2, U1.2 (OUT)
FB\: P6.T, R1.1, R2.2, U1.3 (FB)
GND: B1.2A (N), B1.2B (N), C1.1, C2.1, J1.5 (5-GND), J1.6 (5-GND), J1.7 (5-GND), J1.8 (5-GND), J1.9 (5-GND), J1.10 (5-GND), J1.11 (5-GND), P1.T, R2.1, R4.1, U1.7 (TIMER), U1.11 (GND)
unnamed: S1.3 (OFF), U1.4 (/LDOEN)
unnamed: D1.C, U1.6 (/CHRG)
unnamed: D1.A, R3.1
PROG: P4.T, R4.2, U1.8 (IDET), U1.9 (PROG)
VBAT: B1.1A, B1.1B, P5.T, S1.2 (C), U1.1 (BAT)
VBUS: C1.2, J1.1 (1-VCC), P3.T, R3.2, U1.10 (VCC)

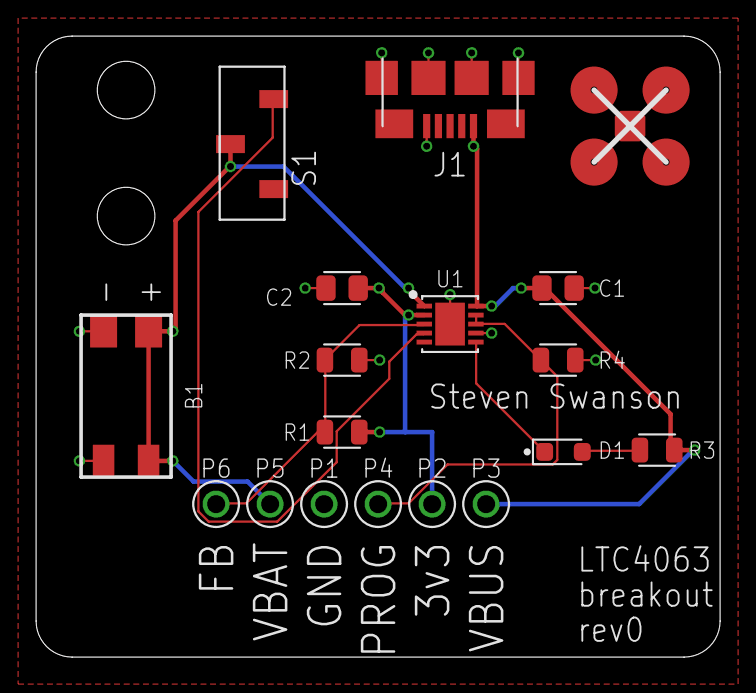
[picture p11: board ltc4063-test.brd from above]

Board: 2 copper layers, 38.0 x 34.5 mm, 18 parts (0 on the bottom side), 9 nets.

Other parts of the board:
U$1: QUADCLASS_LOGO_SMALL

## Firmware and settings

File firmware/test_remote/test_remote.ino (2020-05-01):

#include <radio.h>

#define QUAD_REMOTE_TESTING
#include <quad_remote.h>      // Header file with pin definitions and setup

void knobs_update();
void knob_pressed(bool);
void btn1_pressed(bool);
void btn2_pressed(bool);

void btn_up_pressed(bool down);
void btn_down_pressed(bool down);
void btn_left_pressed(bool down);
void btn_right_pressed(bool down);
void btn_center_pressed(bool down);

void setup() {

     const int RADIO_CHANNEL = 11;        // Channel for radio communications (can be 11-26)
     const int SERIAL_BAUD = 9600 ;        // Baud rate for serial port 
     Serial.begin(SERIAL_BAUD);           // Start up serial
     delay(100);
     quad_remote_setup();

     rfBegin(RADIO_CHANNEL);              // Initialize ATmega128RFA1 radio on given channel

     // The buttons and the knob trigger these call backs.  
     
     knobs_update_cb = knobs_update; 
     knob1_btn_cb = knob_pressed;
     btn1_cb = btn1_pressed;
     btn2_cb = btn2_pressed;
     btn_up_cb =  btn_up_pressed;
     btn_down_cb = btn_down_pressed;
     btn_left_cb =  btn_left_pressed;
     btn_right_cb = btn_right_pressed;
     btn_center_cb =  btn_center_pressed;
     
     knobs_update(); // Initialize the knob

    
    lcd.setBacklight(255, 255, 0); 
    lcd.setContrast(5); //Set contrast. Lower to 0 for higher contrast.
  
    lcd.clear(); //Clear the display - this moves the cursor to home position as well
    lcd.print("Hello, World!");
    
}


int last = 0;
unsigned char magic;

#define INFO_MODE 1
#define CONTROL_MODE 2

int mode = INFO_MODE;

void loop() {
  
     // Read analog values
     // The pins array holds the arduino pin numbers for all the inputs.
     for(char i = 0; i < GIMBAL_AXES; i++) {
	      numbers[i] = analogRead(pins[i]); 
     }
  
     // Read btns
     for(char i = GIMBAL_AXES; i < TOTAL_CHANNELS; i++) {
	      numbers[i] = digitalRead(pins[i]) ? 1023 : 0; 
     }

    for(char i= 0; i < TOTAL_CHANNELS;i++) {
	      Serial.print(numbers[i]);
	      Serial.print(" ");
	  }


     rfWrite((uint8_t*)numbers, sizeof(numbers));

     if (rfAvailable()) {  // If data receievd on radio...
	   digitalWrite(LED3, 1);
	  //delay(100);
	  rfRead(&magic, sizeof(magic));
	  numbers[TOTAL_CHANNELS] = magic;
	  digitalWrite(LED3, 0);
     } else {
	  digitalWrite(LED3, 0);
     }

     // This delay (or having one somewhere) is important.  If we send too
     // fast, the packets will run together on the receive side.
     delay(100);
     
     //lcd.setCursor(12, 1);
     Serial.print(constrain(map(analogRead(PIN_THROTTLE),52,890,7,0), 0, 7));
     Serial.print(" ");
     Serial.print(constrain(map(analogRead(PIN_YAW),140,800,0,7), 0 ,7));
     Serial.print(" ");
     Serial.print(constrain(map(analogRead(PIN_PITCH),140,800,0,7), 0, 7));
     Serial.print(" ");
     Serial.print(constrain(map(analogRead(PIN_ROLL),140,800,0,7), 0, 7));
     Serial.print("\n");

}

void knobs_update() {
  /*
     unsigned char b = knob1.getCurrentPos() *  16;
     unsigned char r = 0;
     unsigned char g = 0;

     lcd.home();
     lcd.clear();
     lcd.print("R");
     lcd.print(r);
     lcd.setCursor(4,0);
     lcd.print(" G");
     lcd.print(g);
     lcd.setCursor(9,0);
     lcd.print(" B");
     lcd.print(b);
     lcd.setCursor(0,1);
     lcd.print("Bat: ");

     if (mode == INFO_MODE) {
	  lcd.print(map(analogRead(BATTERY_SENSE), MIN_BATTERY, MAX_BATTERY, 0, 100));
	  lcd.print("%");
     } else {
	  lcd.print(analogRead(BATTERY_SENSE));
     }
	  
     digitalWrite(LED1,!digitalRead(LED1));
     digitalWrite(LED2,!digitalRead(LED2));
     digitalWrite(LED3,!digitalRead(LED3));
*/
      Serial.println(knob1.getCurrentPos());
    
}


void btn1_pressed(bool down) {
	if(down) {
		Serial.println("btn1");
	}
	
	if (down) {
		Serial.println("changing modes");
		if (mode == INFO_MODE) {
			mode = CONTROL_MODE;
		} else {
			mode = INFO_MODE;
		}
		knobs_update();
	}
}

void btn2_pressed(bool down) {
	if(down) {
		Serial.println("btn2");
	}
}

void knob_pressed(bool down) {
	if(down) {
		Serial.println("knob");
		Serial.println(knob1.getCurrentPos());
	}
}


void btn_up_pressed(bool down) {
	if(down) {
		Serial.println("up");
	}
}

void btn_down_pressed(bool down) {
	if(down) {
		Serial.println("down");
	}
}

void btn_left_pressed(bool down) {
	if(down) {
		Serial.println("left down");
	} else {
    Serial.println("left up");
	}
}

void btn_right_pressed(bool down) {
	if(down) {
		Serial.println("right");
	}
}

	
void btn_center_pressed(bool down) {
	if(down) {
		Serial.println("center");
	}
}

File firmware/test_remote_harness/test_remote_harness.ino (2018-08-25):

/*
  ATmega128RFA1 Dev Board Basic Chat
  by: Jim Lindblom
  SparkFun Electronics
  date: July 3, 2012
  License: Beerware. Feel free to use, reuse, and modify this code
  as you please. If you find it useful, you can buy me a beer.

  This code sets up the ATmega128RFA1's wireless transciever in
  the most basic way possible to serve as a serial gateway.
  Serial into the ATmega128RFA1's UART0 will go out the RF radio.
  Data into the RF radio will go out the MCU's UART0.
*/

#include "radio.h"

#define QUAD_REMOTE_TESTING
#include <quad_remote.h>

int maxes[TOTAL_CHANNELS + 1];
int mins[TOTAL_CHANNELS + 1];

void setup()
{
     Serial.begin(9600);  // Start up serial
     rfBegin(11);  // Initialize ATmega128RFA1 radio on channel 11 (can be 11-26)

     for(int i = 0; i < TOTAL_CHANNELS + 1; i++) {
	  maxes[i] = 0;
	  mins[i] = 2048;
     }
}

int led_state = 0;
char sent_magic = 1;
char received_magic = 0;
bool got_radio = false;
void loop()
{
     int misses = 0;
     for (int i=  0; i < TOTAL_CHANNELS; i++) {
	  if (mins[i] > 256) 
	       misses++;
	  if (maxes[i] < 256)
	       misses++;
	  Serial.print(numbers[i]);
	  Serial.print(" ");
     }
     if (sent_magic > 20) {
	  got_radio = true;
     }
     if (!got_radio) {
	  misses++;
     }
     Serial.print(numbers[TOTAL_CHANNELS]);
     Serial.print(" ");
     Serial.print(misses);
     Serial.print(" ");
     if (misses == 0) {
	  Serial.print("Test passed ");
     }

     if (sent_magic == received_magic) {
	  Serial.print("RADIO! ");
	  sent_magic++;
     }

     if (rfAvailable())  // If data receievd on radio...
	  {
    
	       int r = rfRead((uint8_t*)numbers, sizeof(numbers));
	       received_magic = (uint8_t)numbers[TOTAL_CHANNELS];
    
	       if (r != sizeof(numbers)) {
		    Serial.print(" Short read ");
		    Serial.print(" ");
		    Serial.print(r);
	       } else {
      
		    rfWrite(sent_magic);
      
		    for (int i=  0; i < TOTAL_CHANNELS; i++) {
			 mins[i] = min(mins[i], numbers[i]);
			 maxes[i] = max(maxes[i], numbers[i]);
		    }
	       }
	  }
     Serial.println();
}

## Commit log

2017-03-19 Give the remote its own repo
    [Air Table.scad, BasePlate.brd, Minimal-Driver.brd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]
2017-03-25 Move gimbals to the underside, move leds so they are so bright an annoying
    [controller_board.brd]
2017-03-26 Refinement based on prototype
    [controller_board.brd]
2017-04-01 fix polarity on butons. Connect unconnected pin on batgnd breakouts
    [controller_board.sch]
2017-04-01 Connect AREF to 3.3V
    [controller_board.brd, controller_board.sch]
2017-04-01 remove support for old gimbals
    [BasePlate.brd]
2017-04-01 small tweak it logo position
    [controller_board.brd]
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2017-04-02 space to adjust contrast an LCD and perhaps lower it.
    [BasePlate.brd]
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2017-04-03 adjustments for better plotting
    [controller_board.brd]
2017-05-19 description of fix for receive problem
    [BasePlate.brd, controller_board.brd, controller_board.sch]
2018-03-10 Removed stuff we can do without:
    1. lots of extra headers.
    2. Separate BAT and VCC nets.
    3. leds
    4. big decoupling cap
    5. Proto area
    STuff remaining:
    1. Move to lipo battery?
    2. Fix LCD voltage problem?
    3. Double check button polarity.
    4. Double check cut traces on current boards.
    5. Double check aref.
    [controller_board.brd, controller_board.sch]
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2018-03-10 import a bunch of components from quad schematic. remove arduino breakout
    [controller_board.brd, controller_board.sch]
2018-03-10 cleanup and a few schematic fixes
    [controller_board.brd, controller_board.sch]
2018-03-10 fix gnd issue on ISP header
    [controller_board.brd, controller_board.sch]
2018-03-14 small fixes. going through check list
    [controller_board.brd, controller_board.sch]
2018-03-15 taped out for jlcpcb
    [controller_board.brd, controller_board.sch]
2018-03-15 Rev1-rc1 tape out for 4pcb
    [controller_board.brd]
2018-03-15 Rev1-rc2 tape out for jlcpcb
    [controller_board.brd]
2018-05-12 Removed dedicated ground plane for antenna; merged with L2 ground plane; added ground pour on top of the board. Moved FTDI programming header and mattery connector down.
    Updated silkscreen as Rev2.
    Updated test code to match new hardware
    [controller_board.brd]
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2018-05-13 surface mount buttons and power led
    [controller_board.brd, controller_board.sch]
2018-05-13 Surface mount power switch
    [controller_board.brd, controller_board.sch]
2018-05-13 move power switch out of the way
    [controller_board.brd]
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2018-05-13 smash and reorg most stuff. Add 10uF caps
    [controller_board.brd, controller_board.sch]
2018-05-13 first draft of FTDI integration
    [controller_board.brd, controller_board.sch]
2018-05-14 merged a bunch of parts into lbr. Laid everything out.
    [controller_board.brd, controller_board.sch]
2018-05-14 First draft of power supply test board
    [controller_board.brd, controller_board.sch]
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2018-05-15 cleanup; small fixes; mosfet for power switching; disable charging on sleep
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2018-05-16 I didn't add these before I committed RC1 and then I modified them, so they don't quite match what was ordered. Only difference around the pours/heatsink for the battery charger
    [power_test.brd, power_test.sch, power_test_rc1.bom.csv]
2018-05-16 revert controller board
    [controller_board.brd, controller_board.sch]
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2018-05-30 adjust resistor values after some testing. make GND an High-I net.
    [power_test.brd, power_test.sch, power_test_rc1.bom.csv]
2018-05-30 Move pwren pull up to 3.3V rail in accordance with datasheet
    [power_test.brd, power_test.sch]
2018-05-30 move C13 and FTDI to make it easier to solder on the FTDI.
    [power_test.brd]
2018-05-30 Preliminary implementation of changes:
    Connect VBUS to FTDI directly.
    Connect FTDI regulator to 3.3V rail.
    Remove mosfet, diode, short across J2.
    Still needs clean up to remove uneeded jumpers.
    [power_test.brd, power_test.sch]
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2018-05-31 fix red led polarity
2018-05-31 full breakout for battery charger. remove voltage regulator. Flip one FTDI port. New source switching scheme. Remove various jumpers. Fix Red LEDs
    [power_test.brd, power_test.sch]
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2018-06-05 verified 3.7V opertaion of ftdi regulator. checked circuit on bread board
    [power_test.brd, power_test.sch]
2018-06-05 Initial layout of Mark 3 board and baseplate
    [controller_board.brd, controller_board.sch]
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2018-06-14 Significant redesign to accomodate LCD
    [controller_board.brd, controller_board.sch]
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2018-06-14 Fix stencil fiducial to fill in tcream hole
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2018-06-17 Added rotary encoders, correctly wired LCD, reworked layout.
    [controller_board.brd, controller_board.sch]
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2018-06-19 Adjust encoder height. Gimbal holes. Servo connector placement.
    [controller_board.brd, controller_board.sch]
2018-06-19 fix gimbal wiring in device
    [controller_board.brd]
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2018-06-23 Cleanly support monochrome and RGB LCDs. Put all buttons and encoders on interrupts. New pin assignments. New uCtrl symbol
    [controller_board.brd, controller_board.sch]
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2018-06-24 fix outline
    [controller_board.brd, controller_board.sch]
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2018-06-26 small tweaks; clean up charger heat sink; rc6
    [controller_board.brd]
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2018-06-29 notes from undergrads. Tweak stencil fiducial. Some new parts
    [controller_board.brd, controller_board.sch, controller_board_minimal.brd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]
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2018-07-05 Reduced controls. Increased configurability. Defaults to minimal configuration
    [controller_board.brd, controller_board.sch]
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2018-07-07 fix a few small bugs -- rotate ISP programmer more space around board
    [controller_board.brd, controller_board.sch]
2018-07-08 fix pin ordering on LCD
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2018-07-09 Remove option for 3v3 from FTDI. Cleanup; Edge-mounted switches.
    [controller_board.brd, controller_board.sch]
2018-07-09 Bypass power switch. Rearrange circuit to share input cap on vreg and bat charger
    [controller_board.brd, controller_board.sch]
2018-07-10 first steps toward silkscreen cleanup. Shrunk everything and fixed typos
    [controller_board.brd, controller_board.sch]
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2018-07-11 moved everything to dual LEDs w/ shared resistors.
    [controller_board.brd, controller_board.sch]
2018-07-11 note about using a bigger cap for the reset
    [controller_board.sch]
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2018-08-25 updated test and quadcopter lib code and a critical fix in radio.h rfRead()
    [test_remote.ino, test_remote_harness.ino]
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2018-08-26 rearrange board and add holes in baseplate to make assembly easier
    [controller_board.brd]
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2018-08-26 Swap red and green leds
    [controller_board.brd, controller_board.sch]
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2018-08-26 use trace-connected jumpers. Put them on the back of the board
    [controller_board.brd, controller_board.sch]
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2018-08-28 adjust bat sense resistor values for new aref
    [controller_board.brd, controller_board.sch]
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2018-08-28 Reduce BOM lines by reconfigure reset circuit
    [controller_board.brd, controller_board.sch]
2018-08-28 Rename nets. Increase RF net width to 50mil.
    [controller_board.brd, controller_board.sch]
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2018-08-28 fix one net class.
    [controller_board.brd, controller_board.sch]
2018-08-28 Fix DRC width errors. RC3.
    [controller_board.brd]
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2018-09-06 fix incorrect resistor part number
    [controller_board.sch]
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2018-12-29 logo and missing antenna
    [controller_board.brd, controller_board.sch]
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2019-02-14 Fix color of charger indicator LEDs
    [controller_board.brd, controller_board.sch]
2019-02-15 software updates for Rev 4. Move FTDI over a bit to accomodate battery.
    [controller_board.brd]
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2019-03-02 Update code for v4-rev5. LCD not working.
    [test_remote.ino]
2019-03-08 bump revision number. Run vbat through power switch
    [controller_board.brd, controller_board.sch]
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2019-03-08 enable the LCD again, sort of. Communication is unidirectional, which causes flow control problems when you try to change the backlight
    [test_remote.ino]
2019-03-22 enable ftdi by default. Make power switch non-optional
    [controller_board.brd, controller_board.sch]
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2019-05-07 significant reorg to improve control layout and simplify design
    [controller_board.brd, controller_board.sch]
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2019-05-11 reorg. larger board. More spacious. Strain relief for the battery
    [controller_board.brd, controller_board.sch]
2019-05-11 resolve meaningless merge
    [controller_board.brd, controller_board.sch]
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2019-05-15 All routed with shield gnd to control routing
    [controller_board.brd, controller_board.sch]
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2019-05-20 fix wierd attribute placement
    [multicharger.brd]
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2019-05-31 ADding missing files. Not sure where they went.
    [multicharger.brd, multicharger.sch]
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2019-06-18 0603. Fixed courtyards. chip antenna
    [controller_board.brd, controller_board.sch]
2019-06-18 fix wierd bug.
    [controller_board.brd]
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2019-06-23 cosmetic fixes
    [controller_board.brd, controller_board.sch]
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2019-07-07 cleanup. Avoid leakage on battery sense
    [controller_board.brd, controller_board.sch]
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2020-02-13 new revision for fixed bom
    [controller_board.brd, controller_board.sch]
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2020-05-01 silkscreen updates and restore missing GND test point
    [controller_board.brd, controller_board.sch]
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2020-09-12 missing attribute
    [controller_board.brd, controller_board.sch]
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2020-12-09 Bump version. add missing gerbers for multicharger
    [controller_board.assembly-bom.csv]
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2021-02-20 fix wire bridge
    [controller_board.brd, controller_board.sch]
2021-02-20 fix lint
    [controller_board.brd, controller_board.sch]
2021-02-21 fix attrs
    [controller_board.brd, controller_board.sch]
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2021-02-26 routing fixes
    [controller_board.brd]
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2021-12-31 unknown changes from long ago. And updating drill sizes for bigger screws
    [controller_board.brd, controller_board.sch]
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2023-01-26 Removing AREF & Adding voltage divider for gimbals
    [controller_board.brd, controller_board.sch]
2023-02-02 Remote gerber with ARF fix, Sent to fab Jan-29
    [BOM(controller_board).xls, Digikey_BOM_4(controller_board).csv, controller_board.brd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]
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2023-02-23 Remote controller with fixed TX/RX serial lines
    [BOM(controller_board).xls, Digikey_BOM_4(controller_board).csv, controller_board.brd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]
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
